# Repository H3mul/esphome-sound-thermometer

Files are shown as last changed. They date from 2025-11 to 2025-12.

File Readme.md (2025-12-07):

# Sound Thermometer

A quick ESPHome project that illuminates an addressable LED strip based on sound levels detected by a microphone module.

## Features

- Custom LED effect that lerps between two colors based on sound level
- Configurable sound sensitivity and LED colors via ESPHome webui
- Support for USB C and A power source capability detection
- Safety kill switch via a mosfet to disable the LED load if the power source doesn't support enough current
- Pins for power switch

## Media

https://github.com/user-attachments/assets/a23c17ae-ab65-41b6-94d6-0d3440485dc3

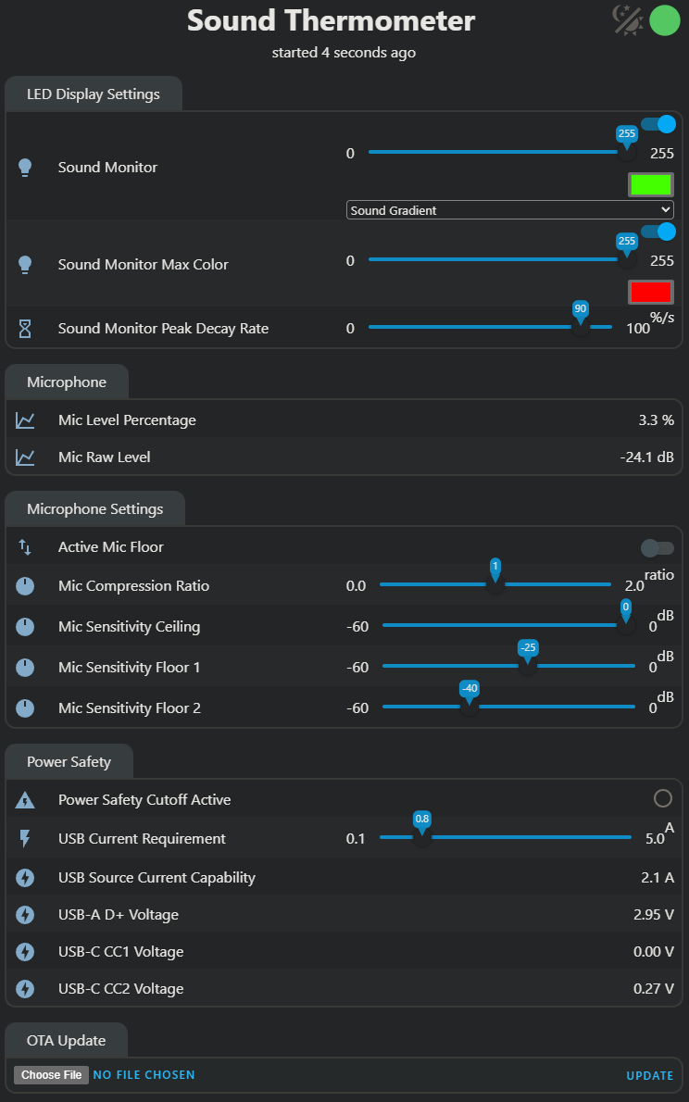
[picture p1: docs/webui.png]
webui


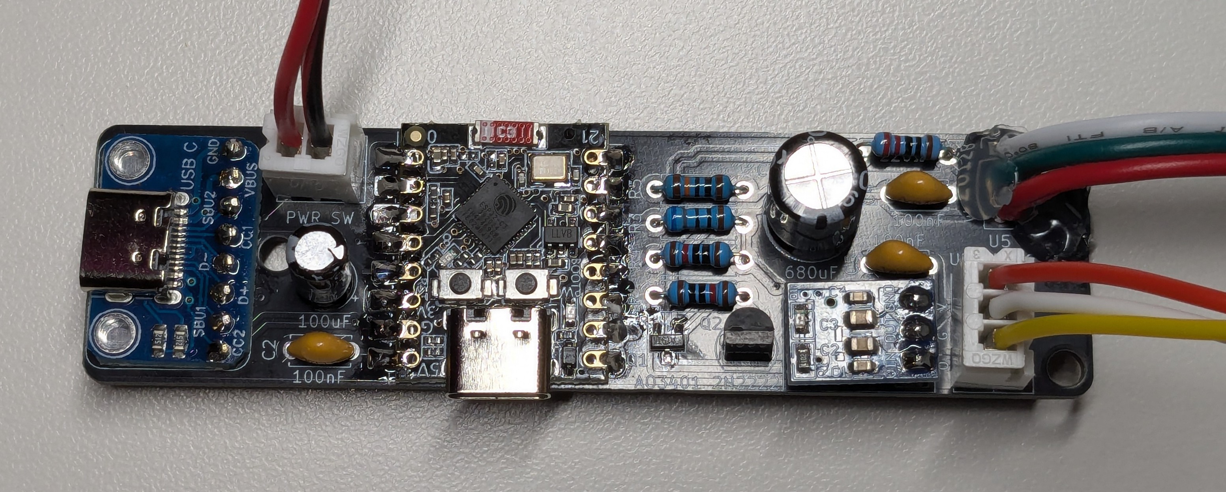
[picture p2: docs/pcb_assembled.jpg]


## Hardware Design

### Schematic Diagram



### PCB Layout



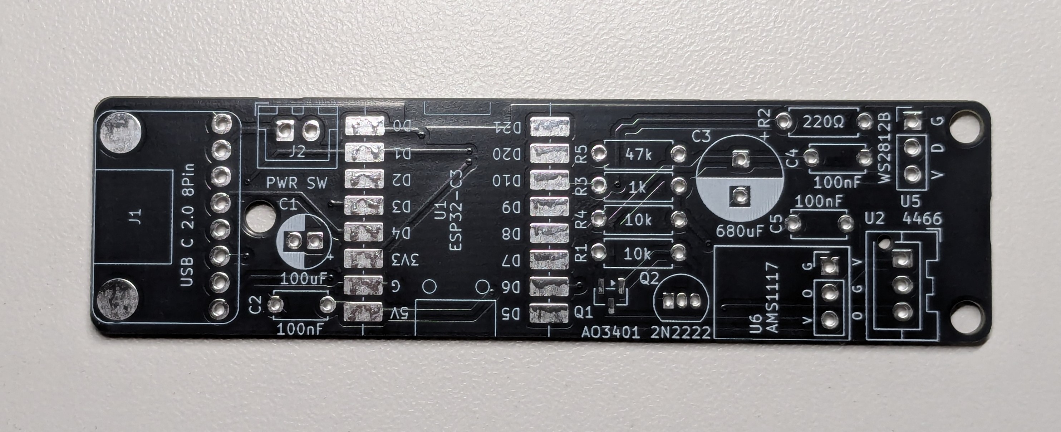
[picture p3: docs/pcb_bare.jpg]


## Components

- Microcontroller (ESP32-C3 Super Mini)
- WS2812B LED strip
- Microphone module with analog out (e.g., MAX9814)
- AMS1117-3.3 Voltage Regulator for clean mic module power
- P-Channel MOSFET for power control (AO3401)
- P2N2222A NPN transistor for mosfet driving
- USB C 8-pin breakout board with 5.1k resistors for CC pins (designating the device as a power drain)
- Bulk and filter capacitors
- A few resistors (see schematic for details)

## ESPHome Installation & Configuration

### Prerequisites

- ESPHome installed on your system
- Home Assistant instance (optional, for integration)
- A compatible microcontroller (as defined in your configuration)
- USB cable for flashing

### Setup Instructions

1. **Clone or download this configuration:**
   ```bash
   git clone https://github.com/H3mul/esphome-sound-thermometer.git
   ```

2. **Create or update your ESPHome configuration file:**
   - Use the provided [`esphome/sound-thermometer-config.yaml`](esphome/sound-thermometer-config.yaml) file in this directory
   - Adjust any pins, WiFi credentials, or device settings as needed
   - Add your own `secrets.yaml` with sensitive information referenced in the config

3. **Flash the device:**
   ```bash
   esphome run esphome/sound-thermometer-config.yaml
   ```

4. **Access the webui:**
   - Once flashed, the device will either connect to your WiFi or create an access point
   - Connect to the same network as the device and access the ESPHome dashboard via the device's IP

## Support & Documentation

For more information about ESPHome configuration, visit:
- [ESPHome Official Documentation](https://esphome.io/)

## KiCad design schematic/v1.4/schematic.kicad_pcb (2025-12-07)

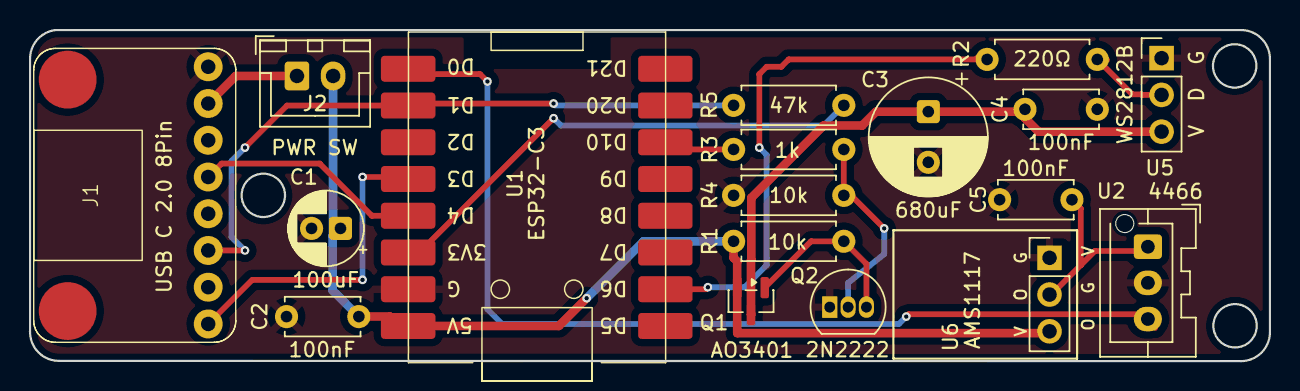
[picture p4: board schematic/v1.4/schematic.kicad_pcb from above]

Board: 4 copper layers, 85.7 x 22.9 mm, 18 parts (0 on the bottom side), 15 nets.

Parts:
C1: 100uF; CP_Radial_D5.0mm_P2.00mm
C2, C4, C5: 100nF; C_Disc_D5.0mm_W2.5mm_P5.00mm
C3: 680uF; CP_Radial_D8.0mm_P3.50mm
J1: USB C 2.0 8Pin; USB_C_8Pin_Breakout
J2: PWR SW; JST_XH_B2B-XH-A_1x02_P2.50mm_Vertical
Q1: AO3401; SOT-23
Q2: 2N2222; TO-92_Inline
R1, R4: 10k; R_Axial_DIN0207_L6.3mm_D2.5mm_P7.62mm_Horizontal
R2: 220Ω; R_Axial_DIN0207_L6.3mm_D2.5mm_P7.62mm_Horizontal
R3: 1k; R_Axial_DIN0207_L6.3mm_D2.5mm_P7.62mm_Horizontal
R5: 47k; R_Axial_DIN0207_L6.3mm_D2.5mm_P7.62mm_Horizontal
U1: ESP32-C3; ESP32-C3 Super Mini
U2: 4466; JST_XA_B03B-XASK-1-A_1x03_P2.50mm_Vertical
U5: WS2812B; PinHeader_1x03_P2.54mm_Vertical
U6: AMS1117; PinHeader_1x03_P2.54mm_Vertical

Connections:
+3.3V: R5.2, U1.3 (3V3)
+5V: C1.1, C2.1, J2.2, Q1.2 (S), R1.1, U1.1 (5V), U6.3 (VI)
+5VD: C3.1, C4.2, Q1.3 (D), U5.3 (VDD)
CC1: J1.A5 (CC1), U1.4 (D4)
CC2: J1.B5 (CC2), U1.5 (D3)
D+: J1.A6 (D+), R5.1, U1.7 (D1)
GND: C1.2, C2.2, C3.2, C4.1, C5.2, J1.A1 (GND), Q2.1 (E), R4.2, U1.2 (GND), U2.2 (GND), U5.1 (GND), U6.1 (ADJ)
LED D: R2.1, U1.10 (D6)
LED SW: R3.1, U1.14 (D10)
MIC: U1.8 (D0), U2.3 (OUT)
unnamed: J1.A4 (VBUS), J2.1
unnamed: Q1.1 (G), Q2.3 (C), R1.2
unnamed: Q2.2 (B), R3.2, R4.1
unnamed: C5.1, U2.1 (VCC), U6.2 (VO)
unnamed: R2.2, U5.2 (DIN)

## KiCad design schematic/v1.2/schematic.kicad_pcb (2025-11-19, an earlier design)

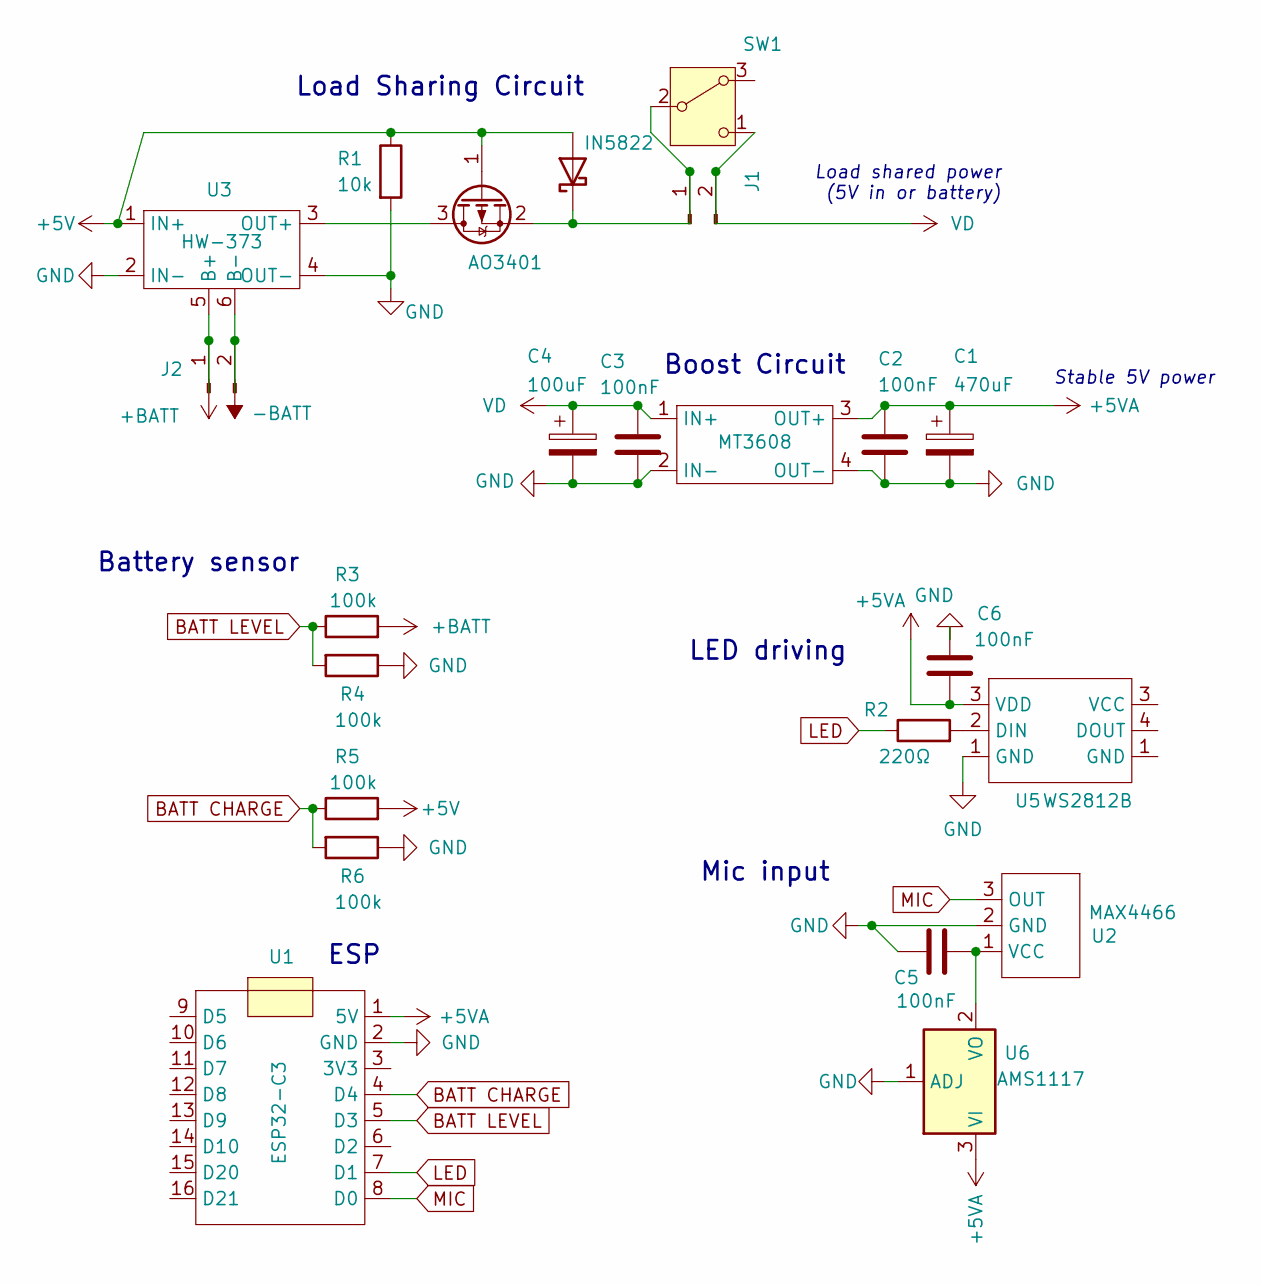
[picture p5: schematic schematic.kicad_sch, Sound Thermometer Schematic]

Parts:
C1: 470uF; CP_Radial_D5.0mm_P2.50mm
C2, C3, C5, C6: 100nF; C_Disc_D5.0mm_W2.5mm_P5.00mm
C4: 100uF; CP_Radial_D6.3mm_P2.50mm
IN5822: D_Schottky; D_DO-27_P12.70mm_Horizontal
J1, J2: Conn_01x02_Pin; JST_XA_B02B-XASK-1_1x02_P2.50mm_Vertical
Q1: AO3401; SOT-23
R1: 10k; R_Axial_DIN0207_L6.3mm_D2.5mm_P7.62mm_Horizontal
R2: 220Ω; R_Axial_DIN0207_L6.3mm_D2.5mm_P7.62mm_Horizontal
R3, R4, R5, R6: 100k; R_Axial_DIN0207_L6.3mm_D2.5mm_P7.62mm_Horizontal
SW1: SW_Nidec_CAS-120A1; JST_XH_B2B-XH-A_1x02_P2.50mm_Vertical
U1: ESP32-C3; ESP32-C3 Super Mini
U2: MAX4466; JST_XA_B03B-XASK-1-A_1x03_P2.50mm_Vertical
U3: HW-373; HW-373 Charge Controller
U4: MT3608; MT3608_Voltage_Booster
U5: WS2812B; PinHeader_1x03_P2.54mm_Vertical
U6: AMS1117; PinHeader_1x03_P2.54mm_Vertical

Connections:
+5V: IN5822.2 (A), Q1.1 (G), R1.1, R5.2, U3.1 (IN+)
+5VA: C1.1, C2.1, C6.1, U1.1 (5V), U4.3 (OUT+), U5.3 (VDD), U6.3 (VI)
+BATT: J2.1, R3.2, U3.5 (B+)
-BATT: J2.2, U3.6 (B-)
BATT CHARGE: R5.1, R6.2, U1.4 (D4)
BATT LEVEL: R3.1, R4.2, U1.5 (D3)
GND: C1.2, C2.2, C3.2, C4.2, C5.2, C6.2, R1.2, R4.1, R6.1, U1.2 (GND), U2.2 (GND), U3.2 (IN-), U3.4 (OUT-), U4.2 (IN-), U4.4 (OUT-), U5.1 (GND), U6.1 (ADJ)
LED: R2.1, U1.7 (D1)
MIC: U1.8 (D0), U2.3 (OUT)
unnamed: IN5822.1 (K), J1.1, Q1.2 (S), SW1.2 (B)
unnamed: Q1.3 (D), U3.3 (OUT+)
unnamed: C5.1, U2.1 (VCC), U6.2 (VO)
unnamed: R2.2, U5.2 (DIN)
VD: C3.1, C4.1, J1.2, SW1.1 (C), U4.1 (IN+)

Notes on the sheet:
Battery sensor
ESP
LED driving
(5V in or battery)
Load shared power
Mic input
Boost Circuit
Stable 5V power
Load Sharing Circuit

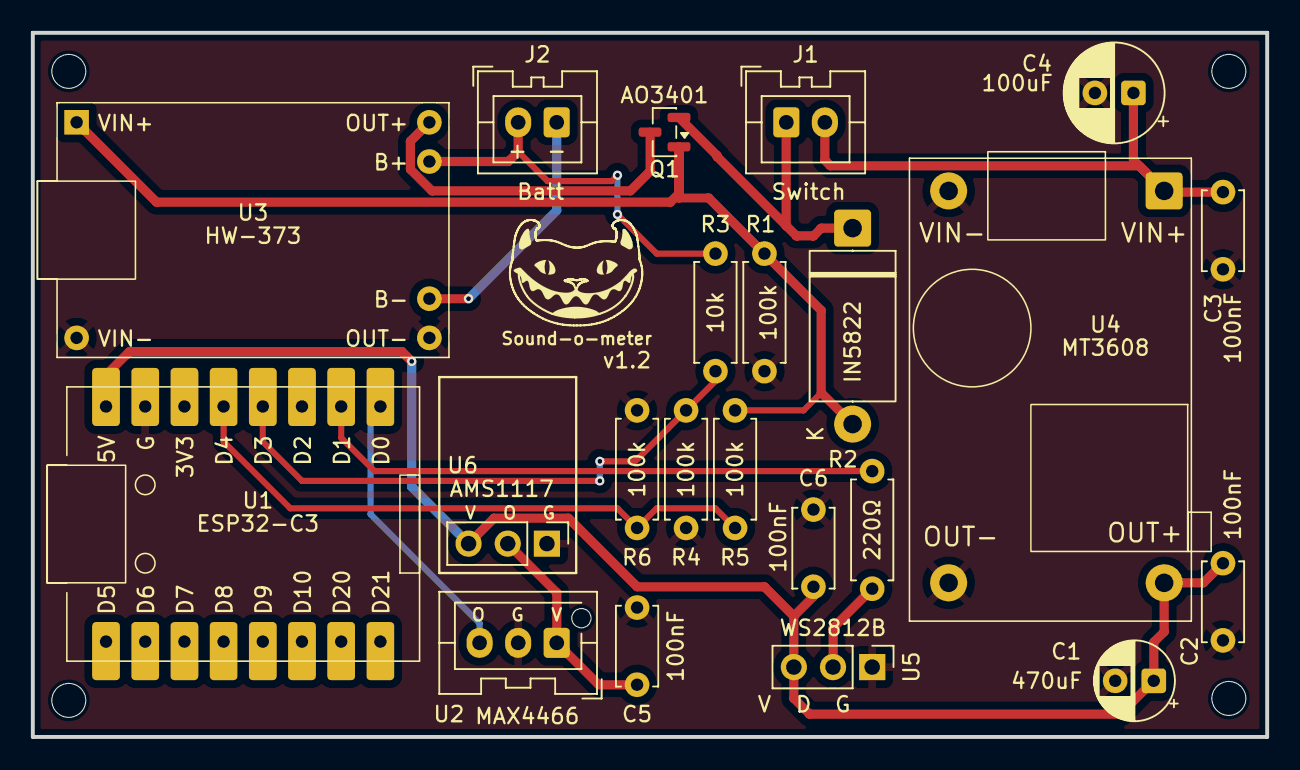
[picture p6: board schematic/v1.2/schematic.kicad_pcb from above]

Board: 4 copper layers, 80.0 x 45.6 mm, 22 parts (0 on the bottom side), 14 nets.

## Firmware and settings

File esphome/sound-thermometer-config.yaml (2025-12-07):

<<: !include ../../base-esphome-configuration.yaml

esphome:
  name: sound-thermometer
  friendly_name: Sound Thermometer
  platformio_options:
    board_build.flash_mode: dio
  on_boot:
    priority: 600
    then:
      - light.turn_on:
          id: sound_level_led

esp32:
  board: esp32-c3-devkitm-1
  variant: esp32c3
  framework:
    type: arduino

# Enable logging
logger:
  level: INFO

wifi:
  networks:
  - ssid: !secret wifi_ssid
    password: !secret wifi_password
  fast_connect: true
  use_address: !secret sound_thermometer_test_local_ip
  # Fallback AP mode when WiFi is unavailable
  ap:
    ap_timeout: 15s
    password: !secret ap_password

external_components:
  - source: github://H3mul/esphome-components
    components: [fakelight]
    
ota:
  - platform: esphome
    password: !secret ota_password
  - platform: web_server
  

web_server:
  port: 80
  local: true
  version: 3
  auth:
    username: !secret web_server_username
    password: !secret web_server_password
  sorting_groups:
    - id: led_settings
      name: "LED Display Settings"
      sorting_weight: 0
    - id: mic_readings
      name: "Microphone"
      sorting_weight: 1
    - id: mic_settings
      name: "Microphone Settings"
      sorting_weight: 2
    - id: power_options
      name: "Power Safety"
      sorting_weight: 3

globals:
  - id: mic_signal_amplitude
    type: float
    restore_value: no
    # 3.3V Peak-to-Peak / 2 = 1.65V RMS reference
    initial_value: "1650.0" #mV

interval:
  - interval: 10s
    startup_delay: 0.5s
    then:
      - script.execute: check_power_safety

script:
  - id: check_power_safety
    then:
      - if:
          condition:
            lambda: 'return id(power_mosfet).state && id(usb_source_rating).state < id(usb_current_requirement).state;'
          then:
            - logger.log:
                format: "SAFETY CUTOFF: USB Source too weak to support current requirement (%.1fA < %.1fA). Main power disabled."
                args: [ 'id(usb_source_rating).state', 'id(usb_current_requirement).state' ]
                level: WARN
            - switch.turn_off: power_mosfet
      - if:
          condition:
            lambda: 'return !id(power_mosfet).state && id(usb_source_rating).state >= id(usb_current_requirement).state;'
          then:
            - logger.log: "Power OK. LEDs Active."
            - switch.turn_on: power_mosfet

switch:
  - platform: gpio
    pin: GPIO10
    name: "Main Power Switch"
    id: power_mosfet
    internal: true
    # Default to OFF to prevent brownout on boot
    restore_mode: ALWAYS_OFF

  - platform: template
    name: "Active Mic Floor"
    id: active_mic_floor
    icon: "mdi:swap-vertical"
    optimistic: true
    restore_mode: RESTORE_DEFAULT_OFF
    web_server:
      sorting_group_id: mic_settings
    on_turn_on:
      then:
        - lambda: |-
            ESP_LOGI("mic_floor", "Switched to Floor 2");
    on_turn_off:
      then:
        - lambda: |-
            ESP_LOGI("mic_floor", "Switched to Floor 1");

binary_sensor:
  - platform: template
    name: "Power Safety Cutoff Active"
    icon: "mdi:flash-triangle"
    id: power_safety_state
    lambda: |-
      if (id(power_mosfet).state) {
        return false; // Power OK
      } else {
        return true;  // Power Cutoff Active
      }
    web_server:
      sorting_group_id: power_options
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

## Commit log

2025-11-09 Add schematic
    [esphome sound thermometer.fzz]
2025-11-14 Add new kicad schematic
    [schematic.kicad_pcb, schematic.kicad_sch]
2025-11-17 Add gerbers
    [schematic-B_Mask.gbs, schematic-B_Paste.gbp, schematic-B_Silkscreen.gbo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]
2025-11-18 Adjust pcb and schematic
    [schematic.kicad_pcb, schematic.kicad_sch]
2025-11-18 Add extra signal resistor, update schematic and pcb
    [schematic.kicad_pcb, schematic.kicad_sch]
2025-11-19 Render + save updated pcb
    [schematic-B_Mask.gbs, schematic-B_Paste.gbp, schematic-B_Silkscreen.gbo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]
2025-11-19 Fix issues with pcb for JLCPCB
    [schematic-B_Mask.gbs, schematic-B_Paste.gbp, schematic-B_Silkscreen.gbo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]
2025-11-19 Update schematic svg
2025-11-19 Add battery sense circuit
    [schematic-B_Mask.gbs, schematic-B_Paste.gbp, schematic-B_Silkscreen.gbo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]
2025-11-20 Add v1.4 usb c version
    [esphome sound thermometer.fzz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]
2025-11-21 Add support for usb c and a power communication with cutoff
    [schematic.kicad_pcb, schematic.kicad_sch]
2025-11-21 Add usb a power support
    [schematic-B_Mask.gbs, schematic-B_Paste.gbp, schematic-B_Silkscreen.gbo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]
2025-11-21 Add D+ pull up
    [schematic-B_Mask.gbs, schematic-B_Paste.gbp, schematic-B_Silkscreen.gbo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]
2025-11-21 Adjust power safety
2025-11-21 Adjust pcb and add icons to webserver
    [schematic-B_Mask.gbs, schematic-B_Paste.gbp, schematic-B_Silkscreen.gbo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]
2025-11-23 Final tweaks to pcb
    [schematic-B_Mask.gbs, schematic-B_Paste.gbp, schematic-B_Silkscreen.gbo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]
2025-11-24 Add pcb svg and updates
    [schematic-B_Mask.gbs, schematic-B_Paste.gbp, schematic-B_Silkscreen.gbo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]
2025-11-24 Final touches before order
    [schematic-B_Mask.gbs, schematic-B_Paste.gbp, schematic-B_Silkscreen.gbo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]
2025-12-07 Add multiple floors with a switcher, and set AP timeout to 15s
2025-12-07 Update pcb drawing
    [schematic.kicad_pcb]
